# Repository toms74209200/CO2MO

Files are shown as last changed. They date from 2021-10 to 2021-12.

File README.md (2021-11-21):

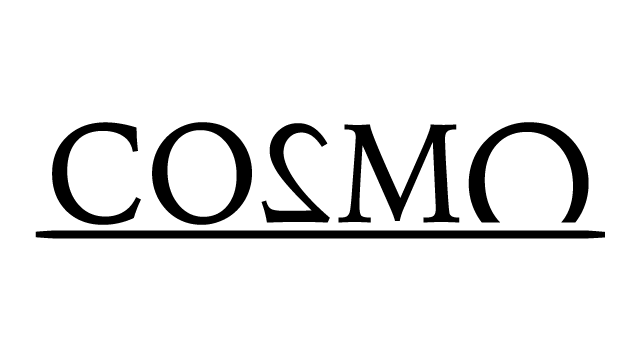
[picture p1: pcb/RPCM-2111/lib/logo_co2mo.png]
CO2MO logo


---



CO2 monitor made with RP2040.

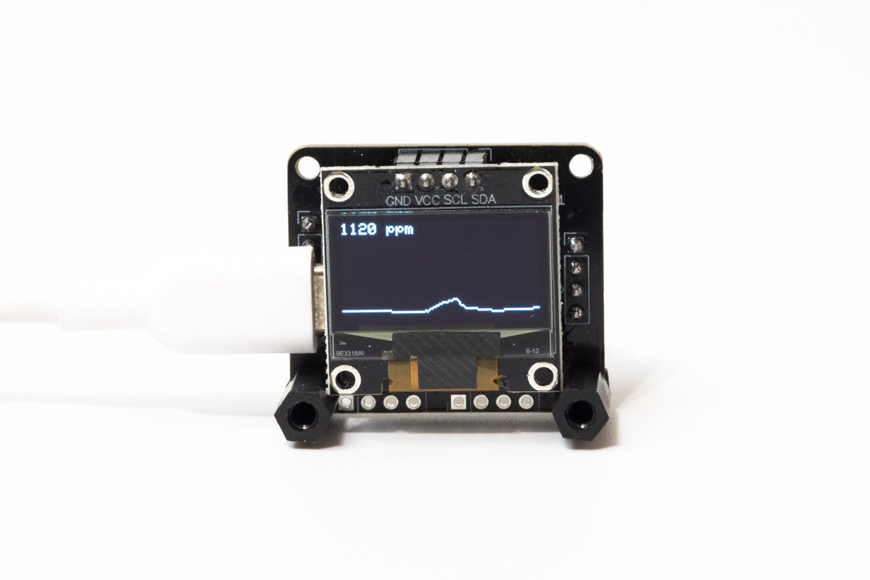
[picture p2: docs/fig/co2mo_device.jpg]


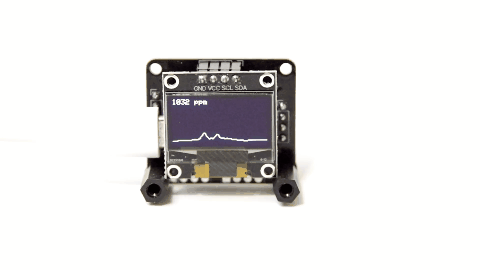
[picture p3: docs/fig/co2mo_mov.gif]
movie


## Devices

- RP2040 development board
- SSD1306 OLED display
- MH-Z19B CO2 sensor

## Schematic

See [RPCM-2111.pdf](pcb/RPCM-2111/RPCM-2111.pdf).

## Build guide

See [build guide](./docs/build_guide_en.md)（[日本語](./docs/build_guide_jp.md)）.

## License

MIT License

## Author

[toms74209200](<https://github.com/toms74209200>)

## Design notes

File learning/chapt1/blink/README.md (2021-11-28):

## Chapt. 1 Hello World

まずはマイコンの基本的な周辺機能を用いてファームウェアによるデバイスの操作方法を学びます.

### 1-1 Lチカ すべての始まり

マイコンの外部インタフェースとしてもっとも簡単なGPIOピンの操作を行い, LEDを点灯させます.

LEDの片側は電源に繋がっており, もう一方がGPIOピンに繋がっています. GPIOピンは `HIGH` と `LOW` の2値を取ることができ[[1](#arduino_constants)], 値を変更することでLEDの点灯を制御します.

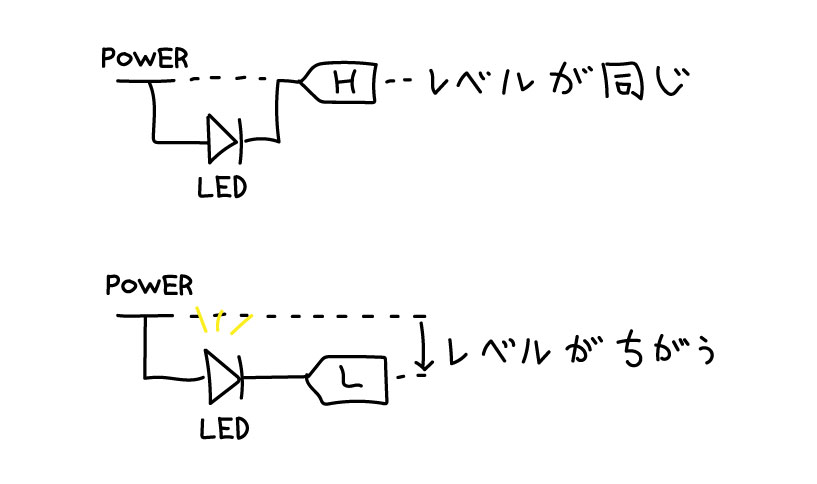
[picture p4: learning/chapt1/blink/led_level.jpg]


ここで使用するマイコン(Tiny 2040) には3色LEDが実装されています. R, G, B の各色に対応するGPIOを制御することでLEDを点灯させることができます.

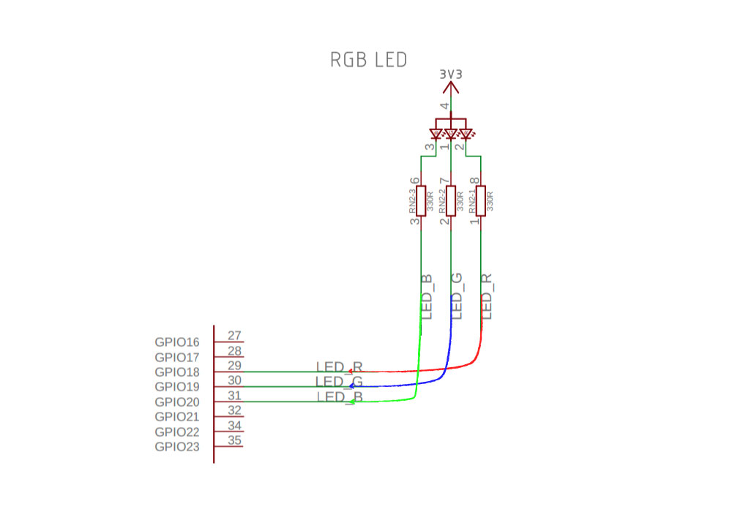
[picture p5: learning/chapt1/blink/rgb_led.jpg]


#### Advanced

- LEDの明るさを変更するには?

#### Refs.

[1]<a name="arduino_constants"/> [Defining Pin Levels: HIGH and LOW | constants - Arduino Reference](https://www.arduino.cc/reference/en/language/variables/constants/constants/#_defining_pin_levels_high_and_low)

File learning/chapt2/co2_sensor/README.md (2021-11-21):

## Chapt. 2 通信

[chapt.1](https://github.com/toms74209200/CO2MO/blob/master/learning/chapt1/hello_world) ではUSBシリアル通信を行いました. ここではGPIOピンと共有している周辺機能を利用して外部装置との通信を行います. 外部装置との通信により外部装置を操作することができます.

### 2-2 センサー入力

ここで使用するCO2センサ(MH-Z19b[[1](#mhz19b_datasheet)]) はデジタルセンサの一種で, 内部にコントローラを持ちます. コントローラがセンサから物理的に意味のある値に変換し, 通信規格にそって通信することでデータを取得することができます. ここではシリアル通信を用いてMH-Z19Bと通信を行います. [chapt.1](https://github.com/toms74209200/CO2MO/blob/master/learning/chapt1/hello_world) でもシリアル通信を使用しましたが, 今回はUSBバス上ではなくGPIOを用いて通信します. UARTによるシリアル通信は HardwareSerial[[2](#arduino_serial)] によって利用することができます. UARTが利用できるピンは予め決まっており, ここでは `GP0`(TX) と `GP1`(RX) を使用しています.

デバイスとの通信を行うには通信規格にのっとって通信するだけでなく, デバイスの動作仕様に従ってデータをやり取りする必要があります. MH-Z19BでもCO2のデータを得るには特定のコマンドを送信し, レスポンスとしてデータを受け取ります. デバイスから受け取ったデータはUARTがレジスタに保存するため, 任意のタイミングでデータを取得することができます.

#### Advanced

- 値の平均値をとるには?

#### Refs.

[1]<a name="mhz19b_datasheet"> [Intelligent Infrared CO2 Module (Model: MH-Z19B) - Winsen](https://www.winsen-sensor.com/d/files/infrared-gas-sensor/mh-z19b-co2-ver1_0.pdf)

[2]<a name="arduino_serial"> [Serial - Arduino Reference](https://www.arduino.cc/reference/en/language/functions/communication/serial/)

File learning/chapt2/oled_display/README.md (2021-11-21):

## Chapt. 2 通信

[chapt.1](https://github.com/toms74209200/CO2MO/blob/master/learning/chapt1/hello_world) ではUSBシリアル通信を行いました. ここではGPIOピンと共有している周辺機能を利用して外部装置との通信を行います. 外部装置との通信により外部装置を操作することができます.

### 2-1 OLED ディスプレイ上での「Hello World」

広く利用されているデバイスではその通信処理がライブラリとして提供されている場合があります. ここで使用するOLEDディスプレイもSSD1306という広く利用されているものを使用します. ここではI2Cという通信規格[[1](#arduino_wire)] を使用してOLEDディスプレイ（のドライバであるSSD1306）との通信を行います. 本来I2Cの通信規格とデバイスの動作仕様に基づいて操作する必要がありますが, 公開されているライブラリを利用することで動作仕様を意識せずに実装することができます.

#### ライブラリのインポート

下記では使用する `Adafruit_SSD1306` と `Adafruit_GFX` ライブラリのインストールを行います[[2](#adafruit_ssd1306)]. 環境構築の際にインストールしている場合は不要です.

メニューで「スケッチ」>「ライブラリをインクルード」>「ライブラリを管理…」を選択し「ライブラリマネージャ」を開きます. 「ライブラリマネージャ」で `Adafruit_SSD1306` と `Adafruit_GFX` を検索しインストールします.

#### ライブラリの利用

`Adafruit_SSD1306` クラスを使用することでOLED ディスプレイを操作することができます. 実際にはマイコンであるRP2040のI2C機能を使用するため, I2C機能を利用できるピンを選択する必要があります. ここでは `GP4`(SDA) と `GP5`(SCL) を使用しています.

ディスプレイの描画はすべてビットマップのため, 文字列の描画もビットマップによって行われています. しかしディスプレイドライバやライブラリを使用することで, それを意識することなくシリアル通信と同じような操作をするだけで文字列を表示することができます.

#### Advanced

- フォントを変更するには?

#### Refs.

[1]<a name="arduino_wire"/> [Arduino - Wire](https://www.arduino.cc/en/reference/wire)

[2]<a name="adafruit_ssd1306"/> [Arduino Library & Examples | Monochrome OLED Breakouts | Adafruit Learning System](https://learn.adafruit.com/monochrome-oled-breakouts/arduino-library-and-examples)

[3] [SSD1306 datasheet](https://cdn-shop.adafruit.com/datasheets/SSD1306.pdf)

[4]<a name="yamorijp_font"> [arduino-examples/main.cpp at master · yamorijp/arduino-examples](https://github.com/yamorijp/arduino-examples/blob/master/ssd1306/src/main.cpp)

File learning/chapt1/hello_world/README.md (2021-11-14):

## Chapt. 1 Hello World

まずはマイコンの基本的な周辺機能を用いてファームウェアによるデバイスの操作方法を学びます.

### 1-2 シリアル通信を使った「Hello World」

このデバイスのマイコン(RP2040)はGPIO以外にも多数の周辺機能を持ちます. 周辺機能により通信規格がサポートされているため, ファームウェア上ではほとんど通信規格を意識することなく実装することができます.

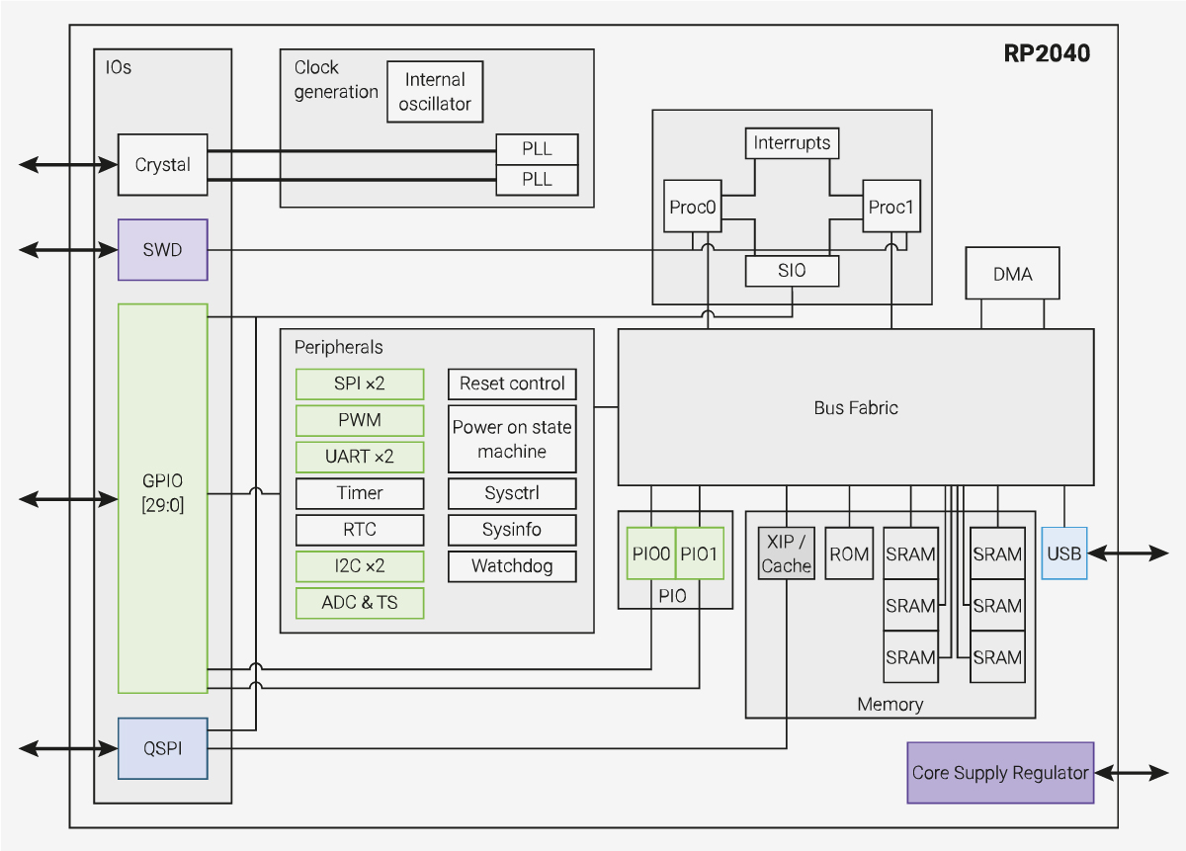
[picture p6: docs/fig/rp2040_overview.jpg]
rp2040_overview


[RP2040 Datasheet](https://datasheets.raspberrypi.com/rp2040/rp2040-datasheet.pdf)

ここではUSBバスプロトコル上でシリアル通信(UART)を行います. 周辺機能とライブラリによりUSBバスプロトコルを意識することなく, PCとのシリアル通信を行うことができます. ソースコードを書き込んだあと, メニューの「ツール」>「シリアルモニタ」を開くと, デバイスから文字が送られてきていることが確認できます.

このときうまくいかない場合は以下の点を確認しましょう.

- 「ツール」>「シリアルポート」は該当のデバイスになっているか.
- 「シリアルモニタ」のボーレートは適切な数値になっているか.

#### Advanced

- PCから送信したデータを扱うには?

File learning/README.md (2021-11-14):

## Learning contents

| Content                                                       |
| ------------------------------------------------------------- |
| Chapt. 1 Hello World                                          |
| [1-1 Blink; beginning of everything](chapt1/blink)            |
| [1-2 Hello World by serial communication](chapt1/hello_world) |
| Chapt. 2 Device communitcation                                |
| [2-1 Hello World on OLED](chapt2/oled_display)                |
| [2-2 Senor input](chapt2/co2_sensor)                          |
| Chapt.3 CO2 monitor                                           |
| [3-1 Diplay data](chapt3/co2_monitor)                         |
| [3-2 Display chart](chapt3/co2_chart)                         |

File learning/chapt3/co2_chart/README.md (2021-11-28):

## Chapt. 3 CO2 モニタを作る

これまで使ってきた機能を組み合わせてCO2モニタを作成します. 

### 3-2 グラフを表示する

ここではCO2の値を直接表示するだけでなく, 値をグラフとして描画します. グラフの描画にはライブラリの図形描画機能[[1](#adafruit_graphics)] を使います. 

まずは簡単のために, 1点を描画することを考えます. ある 1点を描画するには横方向の位置と縦方向の位置が必要です. 横方向の位置は画面の横幅を次々与えるだけです. 縦方向の位置はCO2の値と画面の縦の長さから計算する必要があります. つまり画面の上端と下端がそれぞれCO2の値の最大値と最小値となるように計算します. 

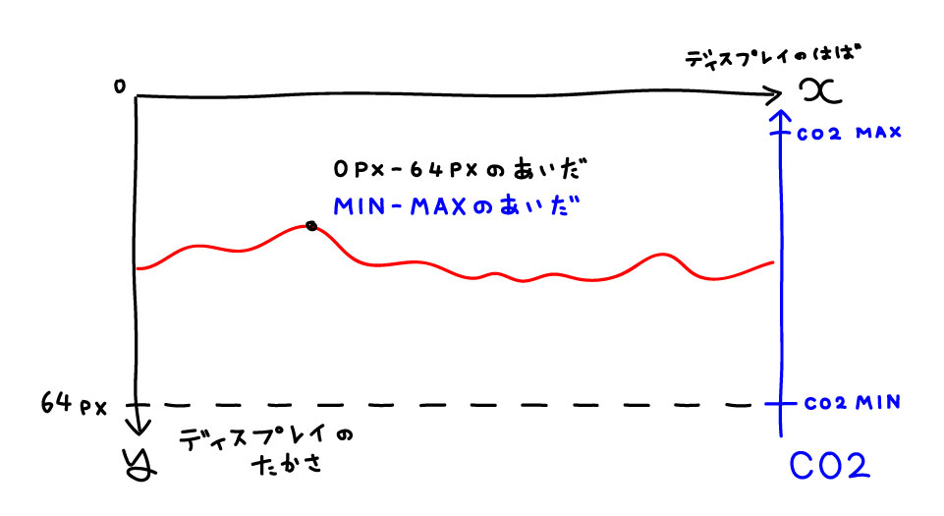
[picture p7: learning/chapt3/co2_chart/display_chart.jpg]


CO2濃度は屋外で 400ppm前後でありこれが最低値です. またMH-Z19Bでは 5000ppmまで測定することができますが, 一般的に 3000ppmを超えることはまれです. また厚生労働省では屋内のCO2濃度を 1000ppm以下に維持するよう奨励しています[[3](#mhlw_go)].

### Refs.

[1]<a name="adafruit_graphics"> [Graphics Primitives | Adafruit GFX Graphics Library | Adafruit Learning System](https://learn.adafruit.com/adafruit-gfx-graphics-library/graphics-primitives)

[2]<a name="kisho_co2"> [気象庁 | 二酸化炭素濃度の経年変化](https://ds.data.jma.go.jp/ghg/kanshi/ghgp/co2_trend.html)

[3]<a name="mhlw_go"> [「換気の悪い密閉空間」を改善するための換気の方法（リーフレット）（令和2年4月3日改訂）［PDF形式：278KB］](https://www.mhlw.go.jp/content/10900000/000618969.pdf)

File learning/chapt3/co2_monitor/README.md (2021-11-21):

## Chapt. 3 CO2 モニタを作る

これまで使ってきた機能を組み合わせてCO2モニタを作成します. 

### 3-1 データを表示する

まずはそのままCO2の値をそのまま表示します. OLEDディスプレイの操作（[2-1 OLED ディスプレイ上での「Hello World」](https://github.com/toms74209200/CO2MO/blob/master/learning/chapt2/co2_sensor)）では文字列をそのまま入力しましたがCO2の値は数値型で扱うため型の変換が必要です.

表示がうまくいかないときはUSBシリアルポートを用いてプリントデバッグを使いましょう.

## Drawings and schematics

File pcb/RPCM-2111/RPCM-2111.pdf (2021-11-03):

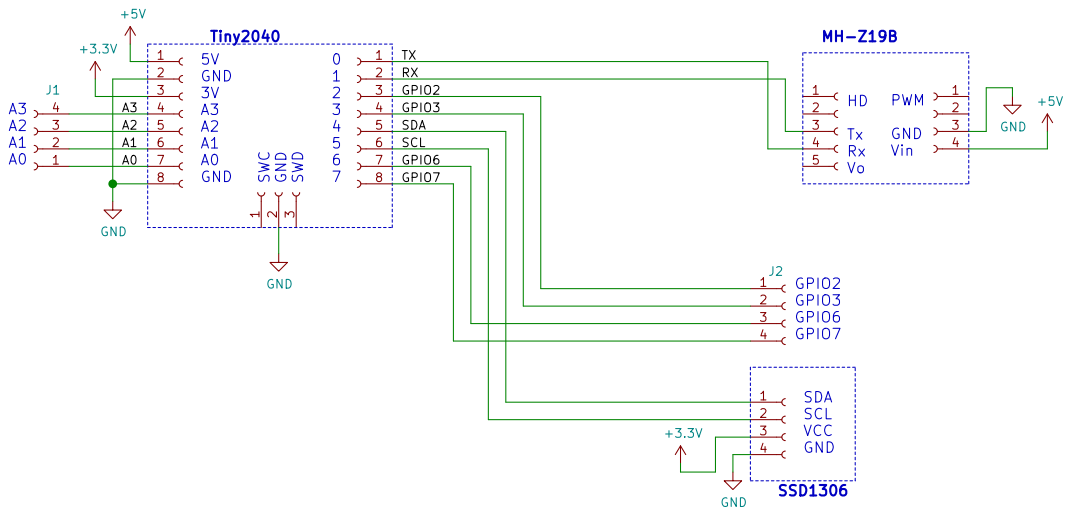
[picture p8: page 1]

Id: 1/1 Title: CO2 monitor File: RPCM-2111.sch Sheet: / Toms

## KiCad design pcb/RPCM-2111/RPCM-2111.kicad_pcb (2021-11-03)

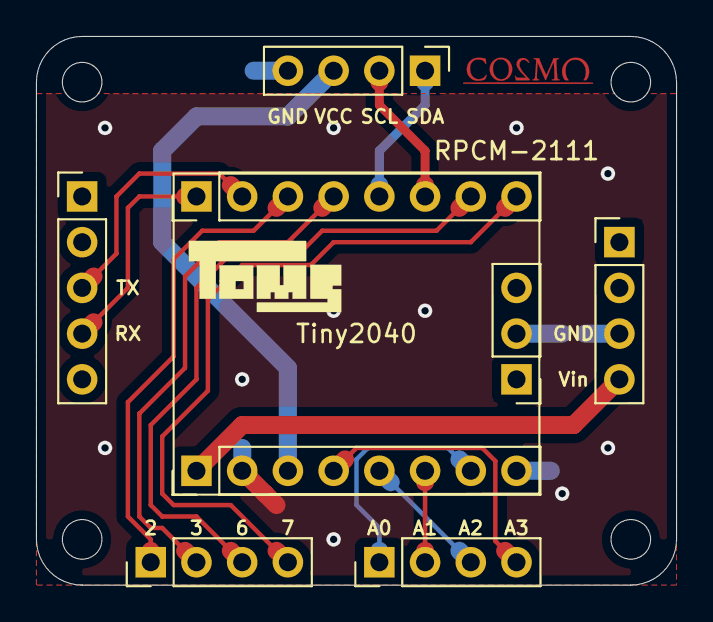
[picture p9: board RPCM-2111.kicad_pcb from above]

Board: 2 copper layers, 35.6 x 30.5 mm, 8 parts (0 on the bottom side), 15 nets.

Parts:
J1, J2, J5, J8: Conn_01x04_Female; PinHeader_1x04_P2.54mm_Vertical
J3, J4: Conn_01x08_Female; PinHeader_1x08_P2.54mm_Vertical
J6: Conn_01x05_Female; PinHeader_1x05_P2.54mm_Vertical
J7: Conn_01x03_Female; PinHeader_1x03_P2.54mm_Vertical

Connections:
+3V3: J3.3, J8.3
+5V: J3.1, J5.4
/A0: J1.1, J3.7
/A1: J1.2, J3.6
/A2: J1.3, J3.5
/A3: J1.4, J3.4
/GPIO2: J2.1, J4.3
/GPIO3: J2.2, J4.4
/GPIO6: J2.3, J4.7
/GPIO7: J2.4, J4.8
/RX: J4.2, J6.3
/SCL: J4.6, J8.2
/SDA: J4.5, J8.1
/TX: J4.1, J6.4
GND: J3.2, J3.8, J5.3, J7.2, J8.4

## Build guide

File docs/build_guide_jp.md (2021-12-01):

# PR2040 CO2 モニタ ビルド ガイド

## 組み立て

## 環境構築

このプロジェクトでは C/C++ とArduino IDE を用いて開発を行います. 本項ではこれらを用いてデバイスの開発環境の構築を行います.

### C/C++ 開発環境の構築

#### Arduino IDE を使う

**Arduino IDE のインストール**

Arduino IDE をインストール.

[Software | Arduino](https://www.arduino.cc/en/software)

macOS では Homebrew を使ってインストールできます.

```bash
$ brew install --cask arduino
```

**ボードライブラリの追加**

1. メニューで「ファイル」>「環境設定」を選択し, 「追加のボードマネージャのURL」に以下のURLを追加します.

```
https://github.com/earlephilhower/arduino-pico/releases/download/global/package_rp2040_index.json
```

2. メニューから「ツール」>「ボード」>「ボードマネージャ...」を選択し「ボードマネージャ」を開き,  `Raspberry Pi Pico/RP2040` を検索しインストールします

**ライブラリの追加**

メニューで「スケッチ」>「ライブラリをインクルード」>「ライブラリを管理…」を選択し「ライブラリマネージャ」を開きます. 「ライブラリマネージャ」で `Adafruit_SSD1306` と `Adafruit_GFX` を検索しインストールします.

**ボードの設定**

ファームウェアを書き込む前に対象となる端末の設定を行います. メニューの「ツール」にある項目を以下のように設定してください. ただしシリアルポートはファームウェア書き込み後シリアルポートを有効にしなければ選択できません. デバッグ実行をする場合は「Optimize」, 「RTTI」, 「Debug Port」を適宜指定します.

| 項 | 値 |
| --- | --- |
| ボード | Adafruit QT Py RP2040  |
| Flash Size | 8MB (no FS) |
| CPU Speed | 133 MHz |
| Optimize | Small (-Os) (standard) |
| RTTI | Disabled |
| Debug Port | Disabled |
| Debug Level | なし |
| USB Stack | Pico SDK |
| シリアルポート | N/A（選択不可） |

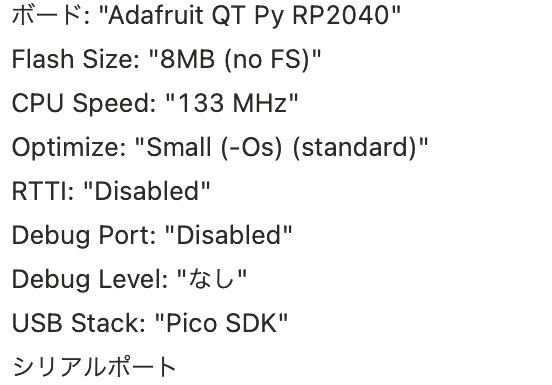
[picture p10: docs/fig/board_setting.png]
board setting


**書き込み方法**

「BOOT」スイッチを押しながらUSBに接続します. 「デバイスマネージャ(Windows)」「システム情報(macOS)」で「RP2 Boot」が接続していることを確認してください. 

メニューで「ファイル」>「スケッチ例」>「rp2040」>「Temperature」を選択.

メニューの「ツール」>「シリアルポート」には表示されません. そのまま書き込み, 書き込みに成功するとUSBの接続が切れシリアルポートとして認識されます.

---

開発基板(Tiny 2040)の詳細は公式サイトを確認ください.

[Tiny 2040 – Pimoroni](https://shop.pimoroni.com/products/tiny-2040)  
https://shop.pimoroni.com/products/tiny-2040

tiny-2040-pinout-diagram

[Tiny 2040 chematic](https://cdn.shopify.com/s/files/1/0174/1800/files/Tiny2040_PIM558_schematic.pdf)  
https://cdn.shopify.com/s/files/1/0174/1800/files/Tiny2040_PIM558_schematic.pdf

**参考**

- [earlephilhower/arduino-pico: Raspberry Pi Pico Arduino core, for all RP2040 boards](https://github.com/earlephilhower/arduino-pico)

- [Arduino IDEでRaspberry Pi Picoの開発環境を構築 | TomoSoft](https://tomosoft.jp/design/?p=43370)

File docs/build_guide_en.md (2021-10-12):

# PR2040 CO2 monitor build guide

## Chapt. 0 Setup

-  [Raspberry Pi Documentation - MicroPython](https://www.raspberrypi.com/documentation/microcontrollers/micropython.html)

- [Raspberry Pi Documentation - The C/C++ SDK](https://www.raspberrypi.com/documentation/microcontrollers/c_sdk.html)

## Chapt. 1 Hello World

### 1-1 Blink; beginning of everything

### 1-2 Hello World by serial communication

## Chapt. 2 Device communitcation

### 2-1 Hello World on OLED

### 2-2 Senor input

## Chapt.3 CO2 monitor

### 3-1 Diplay data

### 3-2 Display chart

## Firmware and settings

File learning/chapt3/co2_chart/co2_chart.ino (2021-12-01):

/**
 * @file co2_chart.ino
 * @brief CO2 chart monitor
 * 
 * Copyright (c) 2021 toms74209200
 * This software is released under the MIT License.
 * http://opensource.org/licenses/mit-license.php
 */

#include <vector>

#include <Wire.h>
#include <Adafruit_GFX.h>
#include <Adafruit_SSD1306.h>

#include "mhz19b_uart.h"

#define LED_R 18
#define LED_G 19
#define LED_B 20

#define RX_PIN 1
#define TX_PIN 0

#define OLED_SCL_PIN 5
#define OLED_SDA_PIN 4
#define SCREEN_WIDTH 128 // OLED display width, in pixels
#define SCREEN_HEIGHT 64 // OLED display height, in pixels
#define OLED_RESET     -1 // Reset pin # (or -1 if sharing Arduino reset pin)
Adafruit_SSD1306 display(SCREEN_WIDTH, SCREEN_HEIGHT, &Wire, OLED_RESET);

constexpr unsigned long INTERVAL = 1*60*1000;
constexpr uint16_t CHART_DATA_OFFSET = 14;
constexpr uint16_t CHART_DATA_HIGHT = SCREEN_HEIGHT - 14;
constexpr uint16_t CHART_DATA_MIN = 350;
constexpr uint16_t CHART_DATA_MAX = 3000;

std::vector<uint16_t> co2_data_vector(SCREEN_WIDTH);

void setup() {
  pinMode(LED_R, OUTPUT);
  pinMode(LED_G, OUTPUT);
  pinMode(LED_B, OUTPUT);

  led_off(LED_R);
  led_off(LED_G);
  led_off(LED_B);

// Debug USB serial
  Serial.begin(115200);

// CO2 sensor serial port
  init_co2(RX_PIN, TX_PIN);

  Wire.setSDA(OLED_SDA_PIN);
  Wire.setSCL(OLED_SCL_PIN);

  if (!display.begin(SSD1306_SWITCHCAPVCC, 0x3C)) {
    Serial.println("SSD1306 allocation failed");
    while(1);
  }

  display.clearDisplay();
  display.setTextColor(WHITE);
  display.display();

  delay(10*1000);
}

void loop() {
  uint16_t co2_data = get_co2();

  Serial.print(co2_data);
  Serial.print("\n");

  char display_data[10];
  sprintf(display_data, "%d ppm", co2_data);

  display.clearDisplay();
  display.setCursor(0, 0);
  display.println(display_data);

  if (co2_data_vector.size() == SCREEN_WIDTH) {
    co2_data_vector.erase(co2_data_vector.begin());
    co2_data_vector.push_back(co2_data);
    for (uint8_t i = 1; i < SCREEN_WIDTH; i++) {
      plot_data(i - 1, i, co2_data_vector[i-1], co2_data_vector[i]);
    }
  } else {
    co2_data_vector.push_back(co2_data);
    uint8_t data_size = co2_data_vector.size();
    for (uint8_t i = 1; i < data_size; i++) {
      plot_data(i - 1, i, co2_data_vector[i-1], co2_data_vector[i]);
    }
  }
  display.display();

  // Interval
  delay(INTERVAL);
}

void led_on(int pin) {
  digitalWrite(pin, LOW);
}

void led_off(int pin) {
  digitalWrite(pin, HIGH);
}

/**
 * @brief plot a pair data
 * @param[in] display_x0 1st position of the pair
 * @param[in] display_x1 2nd position of the pair
 * @param[in] data0 1st data of the pair
 * @param[in] data1 1nd data of the pair
 */
void plot_data(uint16_t display_x0, uint16_t display_x1, uint16_t data0, uint16_t data1) {
  uint16_t display_y0 = SCREEN_HEIGHT + (((data0 - CHART_DATA_MIN) * CHART_DATA_OFFSET) / CHART_DATA_MAX) - (((data0 - CHART_DATA_MIN) * CHART_DATA_HIGHT) / CHART_DATA_MAX);
  uint16_t display_y1 = SCREEN_HEIGHT + (((data1 - CHART_DATA_MIN) * CHART_DATA_OFFSET) / CHART_DATA_MAX) - (((data1 - CHART_DATA_MIN) * CHART_DATA_HIGHT) / CHART_DATA_MAX);
  display.drawLine(display_x0, display_y0, display_x1, display_y1, WHITE);
}

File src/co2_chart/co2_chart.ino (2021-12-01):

/**
 * @file co2_chart.ino
 * @brief CO2 chart monitor
 * 
 * Copyright (c) 2021 toms74209200
 * This software is released under the MIT License.
 * http://opensource.org/licenses/mit-license.php
 */

#include <vector>

#include <Wire.h>
#include <Adafruit_GFX.h>
#include <Adafruit_SSD1306.h>

#include "logo_co2mo_bitmap.h"
#include "DigitalFilter.h"
#include "src/LedController/LedController.h"
#include "src/TimeUtil/TimeUtil.h"
#include "src/MHZ19B_Controller/MHZ19B_Controller.h"

// Pins
constexpr auto RX_PIN = 1;
constexpr auto TX_PIN = 0;
constexpr auto OLED_SCL_PIN = 5;
constexpr auto OLED_SDA_PIN = 4;

// Display
constexpr auto SCREEN_WIDTH = 128; // OLED display width, in pixels
constexpr auto SCREEN_HEIGHT = 64; // OLED display height, in pixels
constexpr auto OLED_RESET = -1; // Reset pin # (or -1 if sharing Arduino reset pin)
Adafruit_SSD1306 display(SCREEN_WIDTH, SCREEN_HEIGHT, &Wire, OLED_RESET);
constexpr uint16_t CHART_DATA_OFFSET = 14;
constexpr uint16_t CHART_DATA_HIGHT = SCREEN_HEIGHT - 14;
constexpr uint16_t CHART_DATA_MIN = 350;
constexpr uint16_t CHART_DATA_MAX = 3000;
constexpr auto OFFSET_DISPLAY_DATA = 5;

led::Red led_r = led::Red();
led::Green led_g = led::Green();
led::Blue led_b = led::Blue();

co2::MHZ19B_Controller co2_controller = co2::MHZ19B_Controller(RX_PIN, TX_PIN);
std::vector<uint16_t> co2_data_vector(SCREEN_WIDTH);
uint8_t valid_data_pointer = SCREEN_WIDTH;

filter::DigitalFilter diginal_filter;

constexpr unsigned long INTERVAL = time_util::Minutes::toMillis(1);

void setup() {
  led_r.turn_off();
  led_g.turn_off();
  led_b.turn_off();

  co2_controller.init();

  diginal_filter = filter::DigitalFilter(co2_controller.get_co2());

  Serial.begin(115200);

  delay(time_util::Seconds::toMillis(10));
}

// Display setting another core
void setup1() {
  Wire.setSDA(OLED_SDA_PIN);
  Wire.setSCL(OLED_SCL_PIN);

  if (!display.begin(SSD1306_SWITCHCAPVCC, 0x3C)) {
    Serial.println("SSD1306 allocation failed");
    while(1);
  }

  display.clearDisplay();
  display.setTextColor(WHITE);

  display.drawBitmap(0, 0, logo::LOGO_BITMAP, SCREEN_WIDTH, SCREEN_HEIGHT, 1);
  display.display();
}

void loop() {
  uint16_t co2_data = co2_controller.get_co2();

  Serial.println(co2_data);

  uint16_t filtered_data = diginal_filter.get_filtered_data(co2_data);

  Serial.println(filtered_data);

  char display_data[10];
  sprintf(display_data, "%d ppm", filtered_data);

  display.clearDisplay();
  display.setCursor(OFFSET_DISPLAY_DATA, OFFSET_DISPLAY_DATA);
  display.println(display_data);

  co2_data_vector.erase(co2_data_vector.begin());
  co2_data_vector.push_back(filtered_data);

  if (valid_data_pointer == 0) {
    for (uint8_t i = 1; i < SCREEN_WIDTH; i++) {
      plot_data(i - 1, i, co2_data_vector[i-1], co2_data_vector[i]);
    }
  } else {
    for (uint8_t i = valid_data_pointer; i < SCREEN_WIDTH; i++) {
      plot_data(i - 1, i, co2_data_vector[i-1], co2_data_vector[i]);
    }
    valid_data_pointer--;
  }
  display.display();

  delay(INTERVAL);
}

/**
 * @brief plot a pair data
 * @param[in] display_x0 1st position of the pair
 * @param[in] display_x1 2nd position of the pair
 * @param[in] data0 1st data of the pair
 * @param[in] data1 1nd data of the pair
 */
void plot_data(uint16_t display_x0, uint16_t display_x1, uint16_t data0, uint16_t data1) {
  uint16_t display_y0 = SCREEN_HEIGHT + (((data0 - CHART_DATA_MIN) * CHART_DATA_OFFSET) / CHART_DATA_MAX) - (((data0 - CHART_DATA_MIN) * CHART_DATA_HIGHT) / CHART_DATA_MAX);
  uint16_t display_y1 = SCREEN_HEIGHT + (((data1 - CHART_DATA_MIN) * CHART_DATA_OFFSET) / CHART_DATA_MAX) - (((data1 - CHART_DATA_MIN) * CHART_DATA_HIGHT) / CHART_DATA_MAX);
  display.drawLine(display_x0, display_y0, display_x1, display_y1, WHITE);
}

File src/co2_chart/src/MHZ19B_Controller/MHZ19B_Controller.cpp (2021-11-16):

/**
 * @file MHZ19B_Controller.h
 * @brief MH-Z19B CO2 sensor controller
 * 
 * Copyright (c) 2021 toms74209200
 * This software is released under the MIT License.
 * http://opensource.org/licenses/mit-license.php
 */

#include "MHZ19B_Controller.h"

const byte co2::Constants::START_BYTE = 0xFF;
const byte co2::Constants::REQUEST_SENSOR = 0x01;
const byte co2::Constants::READ_CO2 = 0x86;
const byte co2::Constants::CHECK_SUM = 0x79;
const uint16_t co2::Constants::UART_BAUDRATE = 9600;
const uint16_t co2::Constants::TEMPERATURE_OFFSET = 40;

co2::MHZ19B_Controller::MHZ19B_Controller(const byte rx, const byte tx) {
  MHZ19B_Controller::rx = rx;
  MHZ19B_Controller::tx = tx;
}

void co2::MHZ19B_Controller::init() {
  Serial1.setRX(rx);
  Serial1.setTX(tx);
  Serial1.begin(co2::Constants::UART_BAUDRATE);
  byte response[7];
  read_mhz19b(response);
}

uint16_t co2::MHZ19B_Controller::get_co2() {
  byte response[7];

  if (!read_mhz19b(response)) {
    return 0;
  }

  byte responseHigh = response[0];
  byte responseLow = response[1];
  uint16_t co2_data = (responseHigh << 8) + responseLow;
  return co2_data;
}

int16_t co2::MHZ19B_Controller::get_temperature() {
  byte response[7];

  if (!read_mhz19b(response)) {
    return 0;
  }

  int16_t temperature = response[2] - Constants::TEMPERATURE_OFFSET;

  return temperature;
}

bool co2::MHZ19B_Controller::read_mhz19b(byte* response) {
  byte cmd[9] = {Constants::START_BYTE,Constants::REQUEST_SENSOR,Constants::READ_CO2,0x00,0x00,0x00,0x00,0x00,Constants::CHECK_SUM};
  Serial1.write(cmd, 9);
  
  const uint16_t retry_count = 10;
  for (uint16_t i = 1; ; i++) {
    byte buf[2];
    Serial1.readBytes(buf, sizeof(buf));
    if (buf[0] == Constants::START_BYTE && buf[1] == Constants::READ_CO2) {
      break;
    }
    if (i > retry_count) {
      return false;
    }
  }
  byte buf[7];
  Serial1.readBytes(buf, sizeof(buf));
  memcpy(response, buf, sizeof(response));
  return true;
}

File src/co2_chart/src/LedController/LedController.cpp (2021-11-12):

/**
 * @file LedController.cpp
 * @brief LED controller
 * 
 * Copyright (c) 2021 toms74209200
 * This software is released under the MIT License.
 * http://opensource.org/licenses/mit-license.php
 */

#include "LedController.h"

led::Red::Red() {
  pinMode(LED_PIN, OUTPUT);
}
void led::Red::turn_on() {
  digitalWrite(LED_PIN, LOW);
}
void led::Red::turn_off() {
  digitalWrite(LED_PIN, HIGH);
}

led::Green::Green() {
  pinMode(LED_PIN, OUTPUT);
}
void led::Green::turn_on() {
  digitalWrite(LED_PIN, LOW);
}
void led::Green::turn_off() {
  digitalWrite(LED_PIN, HIGH);
}

led::Blue::Blue() {
  pinMode(LED_PIN, OUTPUT);
}
void led::Blue::turn_on() {
  digitalWrite(LED_PIN, LOW);
}
void led::Blue::turn_off() {
  digitalWrite(LED_PIN, HIGH);
}

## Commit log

2021-10-16 :sparkles: add LED blinck code
2021-10-17 :sparkles: add schematic
    [RP2040_CO2_sensor.sch]
2021-10-18 :sparkles: add CO2 sensor
2021-10-19 :sparkles: add decoupling capacitors
    [RP2040_CO2_sensor.sch]
2021-10-19 :sparkles: add footprint
    [RP2040_CO2_sensor.sch]
2021-10-30 :recycle: clean CO2 sensor library
2021-11-01 :sparkles: change schematic
    [RP2040_CO2_sensor.sch]
2021-11-02 :sparkles: add labels at wire in schematic
    [RP2040_CO2_sensor.sch]
2021-11-02 :memo: add board name
    [RP2040_CO2_sensor.sch]
2021-11-02 :sparkles: add PCB layout
    [RP2040_CO2_sensor.kicad_pcb]
2021-11-03 :sparkles: add PCB
    [RP2040_CO2_sensor.kicad_pcb]
2021-11-03 :truck: change PCB project name
    [RPCM-2111.kicad_pcb, RPCM-2111.sch, RPCM-2111_multi.kicad_pcb]
2021-11-03 :pencil2: fix comment in schematic
    [RPCM-2111.sch]
2021-11-03 :recycle: refactor uart module
2021-11-12 :sparkles: add LED controller
2021-11-16 :sparkles: add initialization of CO2 sensor
2021-11-16 :zap: fix to plot initial data
    [co2_chart.ino]
2021-12-01 :sparkles: add digital filter
2021-12-01 :rewind: revert learning code
    [LedController.cpp, co2_chart.ino]
2021-12-05 :sparkles: fix to panelize
    [RPCM-2111_multi.kicad_pcb]
